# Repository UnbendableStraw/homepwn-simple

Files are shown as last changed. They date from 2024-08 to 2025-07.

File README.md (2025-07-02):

# Simple HomePod USB / UART Adapter 
This is a forked / modified repo of el1ng's and tihmstar's homepod adapters. I've modified it to fit different test probes since the E2/B1 probes tend to poke holes. I reverted the shape  of the adapter back to a circle. The alignment tabs are now properly aligned and enabled. The screw holes are now properly lined up. The location of the pin holes also needed slight tweaking, and by widening the width of the pin box it makes a perfect fit!

Also included is my table stand. This can be used as a base to sit your homepod on when upside-down, to prevent scratches on the plastic top. It can also be used to protect the dongle when homepod is placed upright, to support USB Airplay (since the adapter will stick out the bottom and not let the HomePod sit flat on a table)

I sell both of these if you don't want to try making them yourself: https://nicsfix.com/shop

## You Will Need
* 4x M2x6 screws; to screw the adapter plate to the bottom of the homepod. You can tape it down if it is secure. The point is a SECURE connection. The screws that hold the circular plastic frame on top of the logic board work perfectly if you have any spares.
* Pogo pins / test probes (I recommend P75-D2 or P75-J1, I do not recommend the E2 or B1 needle probes, they will poke holes in your pads)
* USB cable to solder to test probes
* If using UART, spare wire to solder to UART test probes, and a USB to **1.8v** UART serial adapter. Recommended to use an adapter with a genuine FTDI chip, like the "DSD TECH SH-U09C5".

# Making It
I hosted a livestream making some adapters if you want some visual reference, not really a guide: https://www.youtube.com/watch?v=fxdIzLTcSnA

Download the Table_Dock_v1.1.1, load it into your preferred slicer, with the homepod side of the dongle facing up, and with support. Then print it!

As shown in the livestream, push the pins into the adapter until the tube of the pogo pin is flush with the adapter.

The pinout of the HomePod's debug port, with the pod upside down, and you looking down at the port, is as follows:

```
                AC PORT
                  ^
                  
| NC | TX | RX | CTRL | D+ | D- | GND |
| NC | NC | NC | GND  | NC | NC | NC  |
```
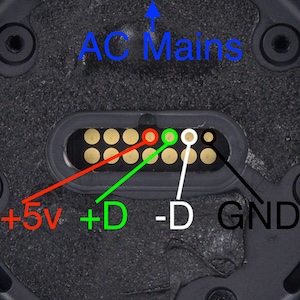
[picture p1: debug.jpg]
pinout


For USB and restoring software, you only need four probes connected to +5v, D+, D-, GND. 

For UART, you need two more probes on the TX and RX, and one for GND. You can share the same GND from the USB line, or another marked GND pad, all the GND pads are internally connected. This is ONLY 1.8v! 3.3 or 5v can cause damage.
 
If you're using probes like the E2 probes, you won't be able to fit the probes in with wires attached, so you'll have to insert the pins into the adapter first, then solder the wires onto them. 

# Using It

You can use this adapter to restore a software bricked first generation HomePod via the restore guide: https://github.com/UnbendableStraw/homepod-restore/

You can also look at the UART console to possibly identify hardware failures preventing the software from operating. To do so;
1. Find your USB UART adapter's address with

`ls /dev/cu.*`

2. "Screen" into your adapter (probably using baud rate 115200) with this, where `tty.usbserial-1` is the adapter you got from the previous command

`screen /dev/tty.usbserial-1 115200`

Tip: You can output your UART logs to a file while still being able to see the logs as they happen. After you enter your screen command, hit control-a, then H. It will output a screenlog.0 file you can rename to .txt

# Warning

If the wrong pins on your adapter touch the wrong pads on the homepod while there is power, it can cause hardware damage. Avoid by simply disconnecting power and usb from pod before removing the adapter from pod.

# USB Airplay for A1639 Apple HomePods

First-generation Apple HomePods can be connected via USB to a Mac and function as a local "USB" Airplay 2 Speaker. This is still Airplay, with all it's pros / cons, just over USB. The HomePod / Mac appear to be creating a virtual network adapter over the USB connection. 

Observations / limitations so far:
* Only seems to work on Macs
* Only seems to work if the HomePod is already set-up. Does not work on a HomePod in Setup Mode
* Does not seem to work if the HomePod is configured as a "Default Output" for an Apple TV
* Needs at least least HomePod Version 14.0? 13.X did not work, so I assume older versions also won't work
* Can play to multiple HomePods via USB using "Airfoil" by Rogue Amoeba (plus other Airplay 2 speakers.) 
* Connecting a stereo-paired HomePod via USB will only play audio to the USB HomePod
* USB Ethernet adapters, even powered ones, by themselves do not appear to work with the HomePod.
* You can turn off all of your wireless radios and it will still work since this is all over the USB cable. 
* Your HomePod's WiFi can be completely dead and this will still work, if your HomePod is already configured.

To use, you need to make or buy a USB adapter for your pod. Whatever you end up doing to get USB access to your HomePod will most likely stick out the bottom, so you need to raise the base of the pod to prevent damage to the adapter or debug port when placing it upright on a table. I have 3d printable adapters and stands you can make or buy here: https://github.com/UnbendableStraw/homepwn-simple/

Video Demos:
* https://twitter.com/UnbendableStraw/status/1836576917077790951
* https://twitter.com/UnbendableStraw/status/1836848399997620624
* https://youtube.com/live/Je3FnzLNufg

Unknowns:
* Can we get a Mac bridge the connection to the rest of your network?
* Can we get it working on Windows / Linux? 
* Can we get _any_ ethernet adapter to work with this?
* Will updates break / remove this in the future?

# Give Up?

You can buy premade adapters, stands, and docks here https://nicsfix.com/shop

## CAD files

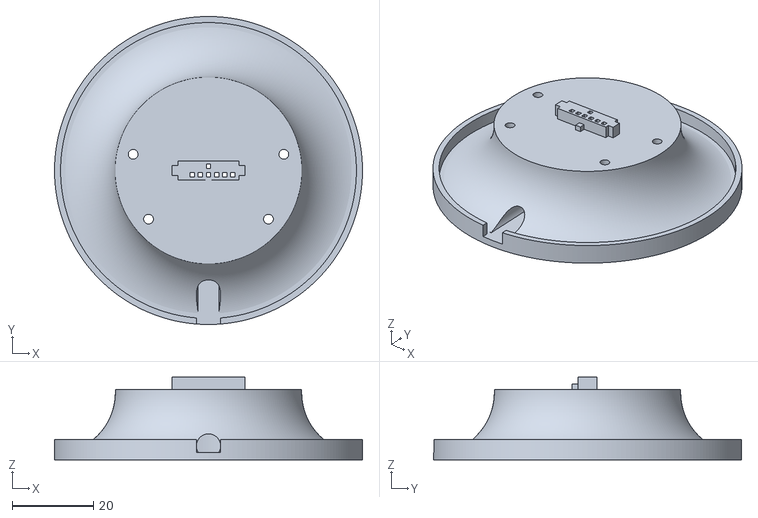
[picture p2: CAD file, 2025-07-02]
Table_Dock_v1.1.1.stl
76.0 x 76.0 x 20.4

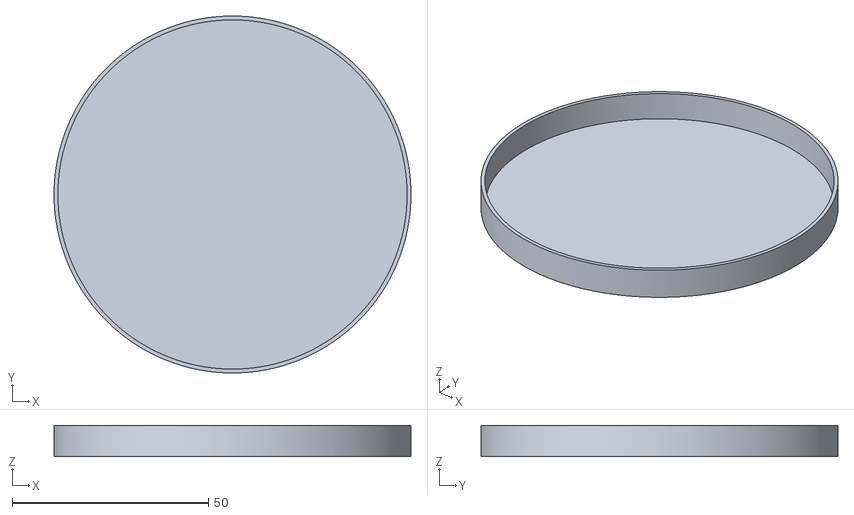
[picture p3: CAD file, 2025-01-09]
TableDockv1_Cap.stl
91.0 x 91.0 x 8.00

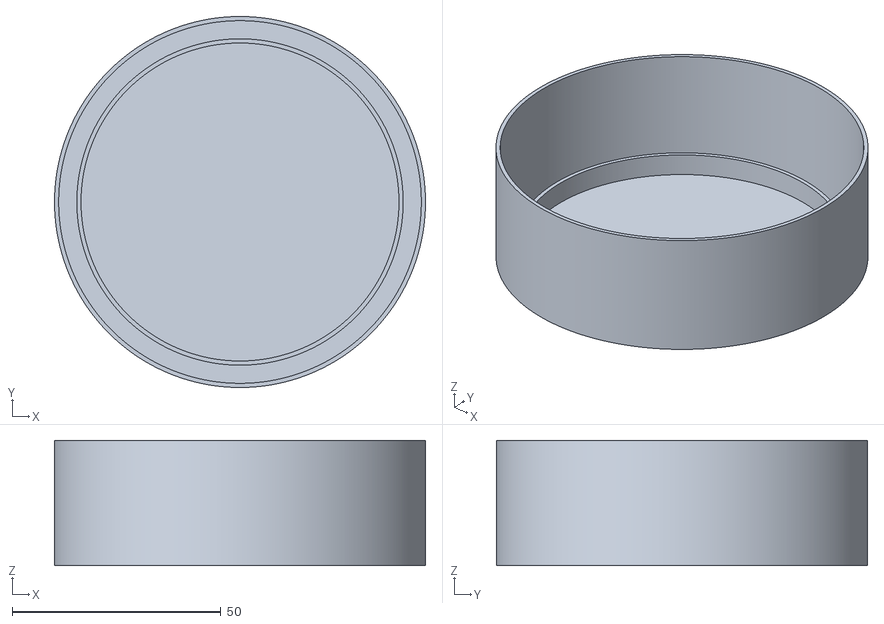
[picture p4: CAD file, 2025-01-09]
TableDockv1_BottomCase.stl
88.8 x 88.8 x 30.0

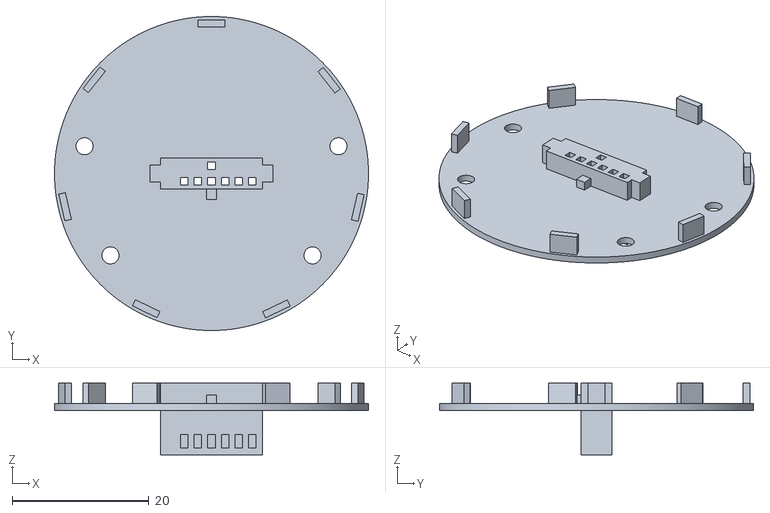
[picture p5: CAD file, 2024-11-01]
Adapterv2.stl
46.0 x 46.0 x 10.5

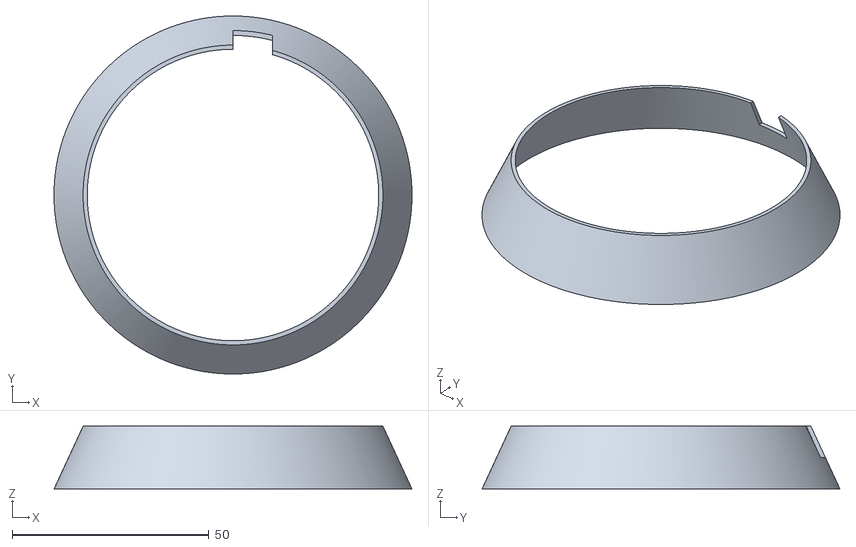
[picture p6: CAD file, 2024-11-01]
TableStand_v3.stl
91.0 x 91.0 x 16.0

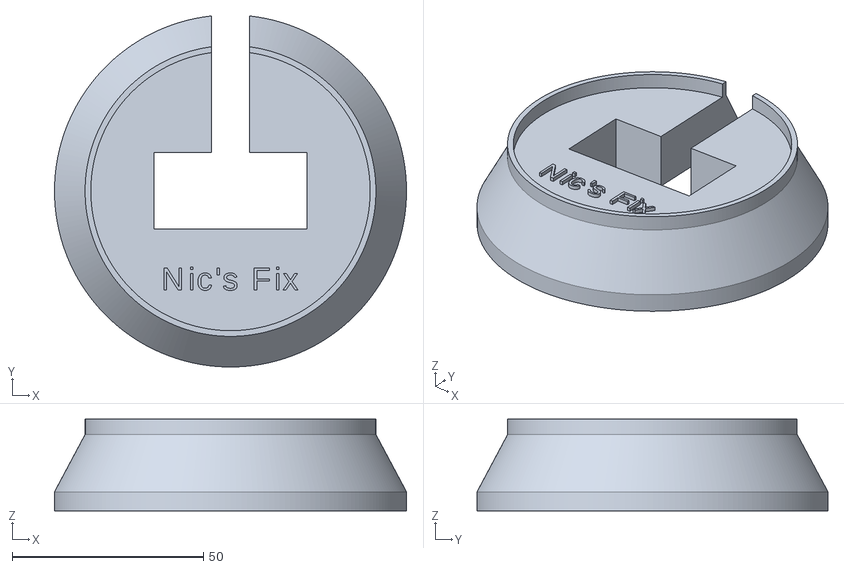
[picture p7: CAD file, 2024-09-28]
table_stand.stl
92.0 x 91.7 x 24.0

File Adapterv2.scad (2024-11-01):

box_length = 15;
box_width = 4.6;
box_height = 5;
box_height_extra = 5.5;
pin_pad = 0.5;
pin_width = 1.1;
nop_width = 1.5;
nop_height = 2;
sidepin_width = 2.5;

// Parameters

base_z_height = 1;

hole_diameter = 2.5;  // Diameter of the holes
hole_depth = 100;    // Depth of the holes (adjusted to be less than the cylinder height)
hole_positions = [
    [14.8, 12],  // Position of hole 1 (x, y)
    [-14.8, 12], // Position of hole 2 (x, y)
    [18.6, -4],  // Position of hole 3 (x, y)
    [-18.6, -4]  // Position of hole 4 (x, y)
];

hole2_diameter = 44;  // Diameter of the holes
hole2_depth = 18;    // Depth of the holes (adjusted to be less than the cylinder height)
hole2_positions = [
    [0, 0, 10]  // Position of hole 4 (x, y, z)
];

// Parameters for the base
top_diameter = 70;
bottom_diameter = 76;
wall_thickness = 1;
top_thickness = 0; // Thickness of the top surface
curve_radius = 15; // Radius of the curve
cutout_position_z = 0; // Z position of the cut-out (make this adjustable)
cutout_height_adjustable = 0.8; // Adjust the height of the cut-out (new parameter)
// New parameter for adjustable base thickness
base_thickness = 0; // Adjust this value to change the thickness of the base

// Parameters for the new ring
ring_height = 4; // Height of the ring
ring_thickness = 2; // Thickness of the ring
ring_inner_diameter = 73; // Inner diameter of the ring
ring_outer_diameter = 76; // Outer diameter of the ring (same as top_diameter)

// Parameters for the cutout in the ring
cutout_position_x = 0; // X position of the cutout center
cutout_position_y = 70; // Y position of the cutout center
cutout_width_in_ring = 4; // Width of the cutout
cutout_height_in_ring = 70; // Height of the cutout (increased to ensure full cut through)

// Set number of facets for smoother cylinders
$fn = 200; // Increases the number of segments to make the cylinder smooth

// Parameters for the bottom ring (same as the top ring)
bottom_ring_height = 2; // Height of the bottom ring
bottom_ring_thickness = 3; // Thickness of the bottom ring
bottom_ring_inner_diameter = 44; // Inner diameter of the bottom ring (same as ring_inner_diameter)
bottom_ring_outer_diameter = 76; // Outer diameter of the bottom ring (same as bottom_diameter)

// Parameters for the top ring =
top_ring_height = 5; // Height of the top ring
top_ring_inner_diameter = 73; // Inner diameter of the top ring (same as ring_inner_diameter)
top_ring_outer_diameter = 76; // Outer diameter of the top ring (same as top_diameter)
module holebox(x = 0, y = 0, z = 0, withHoles = 1){
    translate([x,y,z+1.5]){
        difference(){
            translate([0,0,box_height_extra/2])
            cube([box_length, box_width, box_height+box_height_extra], center = true);
        
            if (withHoles != 0){
                for ( i = [-3 : 3]){
                    if (i != -3){
                        translate([i*2, box_width/2-1.2, 0])
                            cube([pin_width, pin_width, box_height+1+box_height_extra*2], center = true);
                        
                        //sideholes
                        translate([i*2-pin_width/2,box_width/2-1,box_height])
                            cube([pin_width,1,2]);
                    }
                    if (i == 0)
                    translate([i*2, -(box_width/2-1.2), 0])
                        cube([pin_width, pin_width, box_height+1+box_height_extra*2], center = true);
                }
            }
        }
        

        //pin
        translate([0, box_width/2 + nop_width/2, box_height/2-nop_height/2 - pin_pad-0.8])
            cube([nop_width, nop_width, nop_height], center = true);
        translate([0, box_width/2 + nop_width/2, box_height/2-nop_height/2-1])
            cube([nop_width, nop_width, nop_height], center = true);
        
        
        //sidepin right
        translate([box_length/2 + nop_width/2, 0, -0.5])
            cube([nop_width, sidepin_width, box_height-1], center = true);

        //sidepin left
        translate([-(box_length/2 + nop_width/2), 0, -0.5])
            cube([nop_width, sidepin_width, box_height-1], center = true);
        
    }
}

support_len = 2;
support_width = 4;
thickness = 1;

module foot(x = 0, y = 0, z = 0){
    
    leg_len = 3;
    
    translate([x-support_width/2,y-support_len/2,z]){
        translate([0,0,1]);

      


        
        translate([0,-0.5,-3])
        rotate([0,0,0]){
            translate([0,0,-leg_len+2])
                cube([support_width,thickness,leg_len]);                    
        }

    }
}

module footstuff(x = 0, y = 0, z = 1){
    plate_length = box_width + 0;
    plate_width = box_length + 0;
    plate_thickness = 0;
    
    plate_conn = 0;
    
    fplate_radius = 21;

    
    translate([x,y,z]){
    

        



        for ( i = [0:6]){
            rotate([180,0,51.4*i])
                foot(0,-fplate_radius,nop_height);            
        }

    }
}
translate([0, 0, +base_z_height]) {
rotate([0, 0, 0]) {
footstuff();
}
}


module hole(x = 0, y = 0, z = 0){
    translate([x,y,z-1]){
        cylinder(3,1.25,1.25);
    }
}



module base() {
    difference() {
        // Outer part (smooth cone)
        color("lightblue") {
            // Create the smooth cone for the main body
            cylinder(h = base_z_height, r1 = bottom_diameter / 2, r2 = top_diameter / 2);
        }
       // Subtract the curved cut-out from the base without flipping
translate([0, 0,  cutout_position_z]) {
    rotate_extrude($fn = 200)
        translate([bottom_diameter / 2, 0, 0])
            offset(r = curve_radius) {
                // Adjust the height of the cut-out without flipping
                square([curve_radius, cutout_height_adjustable], center = false);
            }
}
    // Cutting hole: a cylinder
    translate([0, -10, 13.1])
    rotate([90,0,900])// Move the cylinder to pass through the cube
    cylinder(h=50, r=2.5, center=false);  // A vertical cylinder with radius 5
            //cut holes out for pins
            translate([0,0,0])
            cube([box_length, box_width, box_height+box_height_extra], center = true);
        
            
                for ( i = [-3 : 3]){
                    if (i != -3){
                        translate([i*2, box_width/2-1, 0])
                            cube([pin_width, pin_width, box_height+1+box_height_extra*2], center = true);
                        
                        //sideholes
                        translate([i*2-pin_width/2,box_width/2-1,box_height])
                            cube([pin_width,1,2]);
                    }
                    if (i == 0)
                    translate([i*2, -(box_width/2-1), 0])
                        cube([pin_width, pin_width, box_height+1+box_height_extra*2], center = true);
                }
                                // Create holes
        for (pos = hole2_positions) {
            translate([pos[0], pos[1], pos[2]]) { // Adjusting the z position to cut through the cylinder
                cylinder(hole2_depth, hole2_diameter / 2, hole2_diameter / 2, center = true); // Create the holes
            }
        }
     // Create holes
        for (pos = hole_positions) {
            translate([pos[0], pos[1], 0]) { // Adjusting the z position to cut through the cylinder
                cylinder(hole_depth, hole_diameter / 2, hole_diameter / 2, center = true); // Create the holes
            }
        }
            
        

    }

}
translate([0, 0, +base_z_height]) {
rotate([180, 0, 0]) {
base();
}
}





rotate([180, 0, 0]) {
    holebox(0, 0, -base_z_height -2);  // Adjust z-position as necessary after flipping
}

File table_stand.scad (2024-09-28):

// Parameters for the base
base_z_height = 15; // Adjustable height of the base
top_diameter = 76;
bottom_diameter = 92;
wall_thickness = 1;
cutout_width = 10;  // Width of the wire cutout (adjusted from diameter)
cutout_length = 10;  // Length of the wire cutout
cutout_depth = 6; // Depth of the cutout from the edge
cutout_height = 20; // Depth of the cutout into the Z axis
top_thickness = 0.6; // Thickness of the top surface

// New parameter for adjustable base thickness
base_thickness = 0; // Adjust this value to change the thickness of the base

// Parameters for the rectangular cutouts
rect_cutout1_width = 40;  // Width of the first rectangular cutout
rect_cutout1_length = 20;  // Length of the first rectangular cutout
rect_cutout_height = base_z_height; // Height of the rectangular cutouts (cuts through the base)

// Parameters for the second rectangular cutout
rect_cutout2_width = 10;  // Width of the second rectangular cutout
rect_cutout2_length = 50;  // Length of the second rectangular cutout
// Position offsets for the second rectangular cutout
rect_cutout2_offset_x = 0;  // X offset for the second rectangular cutout
rect_cutout2_offset_y = 20;  // Y offset for the second rectangular cutout

// New parameter for X-axis offset of the first rectangular cutout
x_offset = -5; // Adjust this value for the X-axis offset

// Parameters for the new ring
ring_height = 4; // Height of the ring
ring_thickness = 2; // Thickness of the ring
ring_inner_diameter = 73; // Inner diameter of the ring
ring_outer_diameter = 76; // Outer diameter of the ring (same as top_diameter)

// Parameters for the cutout in the ring
cutout_position_x = 0; // X position of the cutout center
cutout_position_y = 70; // Y position of the cutout center
cutout_width_in_ring = 10; // Width of the cutout
cutout_height_in_ring = 70; // Height of the cutout (increased to ensure full cut through)

// Set number of facets for smoother cylinders
$fn = 200; // Increases the number of segments to make the cylinder smooth

// Main base shape (truncated cone with smooth sides and a top)
module base() {
    difference() {
        // Outer part (smooth cone) colored in light blue
        color("lightblue")
            cylinder(h = base_z_height, r1 = bottom_diameter / 2, r2 = top_diameter / 2);

        // Wire cutout on the top lip, extending over the edge (changed to rectangle) colored in red
        color("red")
            translate([x_offset, (top_diameter / 2) + (cutout_width / 2) - cutout_depth, base_z_height - cutout_height])
                cube([cutout_width, cutout_length, cutout_height + wall_thickness]);

        // First rectangular cutout centered on the top and cutting through the whole model colored in yellow
        color("yellow")
            translate([-rect_cutout1_width / 2, -rect_cutout1_length / 2, 0]) // Start at the bottom of the model
                cube([rect_cutout1_width, rect_cutout1_length, rect_cutout_height]);

        // Second rectangular cutout positioned by offsets and resizable colored in green
        color("green")
            translate([rect_cutout2_offset_x - rect_cutout2_width / 2, 
                       rect_cutout2_offset_y - rect_cutout2_length / 2, 
                       0]) // Start at the bottom of the model
                cube([rect_cutout2_width, rect_cutout2_length, rect_cutout_height]);
    }
    
    // Create the solid base colored in gray
    color("gray")
        translate([0, 0, -base_thickness]) // Lower the base to ensure it aligns with the ring
            cylinder(h = base_thickness, r = bottom_diameter / 2); // Adjust the height to base_thickness
}

// New ring module with a cutout
module ring() {
    difference() {
        // Outer cylinder for the ring colored in dark blue
        color("darkblue")
            cylinder(h = ring_height, r = ring_outer_diameter / 2);
        
        // Inner cylinder to create the hollow part of the ring colored in light gray
        color("lightgray")
            translate([0, 0, -1]) // Ensure the inner cut does not interfere with other features
                cylinder(h = ring_height + 2, r = ring_inner_diameter / 2);
        
        // Cutout in the ring colored in orange
        color("orange")
            translate([cutout_position_x, cutout_position_y, 1]) // Position the cutout
                cube([cutout_width_in_ring, cutout_height_in_ring, ring_height + 5], center = true); // Ensure the cut goes through fully
    }
}
// Parameters for the bottom ring (same as the top ring)
bottom_ring_height = 5; // Height of the bottom ring
bottom_ring_thickness = 2; // Thickness of the bottom ring
bottom_ring_inner_diameter = 89; // Inner diameter of the bottom ring (same as ring_inner_diameter)
bottom_ring_outer_diameter = 92; // Outer diameter of the bottom ring (same as bottom_diameter)

// New bottom ring module
module bottom_ring() {
    difference() {
        // Outer cylinder for the bottom ring colored in dark blue
        color("darkblue")
            cylinder(h = bottom_ring_height, r = bottom_ring_outer_diameter / 2);
        
        // Inner cylinder to create the hollow part of the ring colored in light gray
        color("lightgray")
            translate([0, 0, -1]) // Ensure the inner cut does not interfere with other features
                cylinder(h = bottom_ring_height + 2, r = bottom_ring_inner_diameter / 2);
                // Cutout in the ring colored in orange
        color("orange")
            translate([cutout_position_x, cutout_position_y, 1]) // Position the cutout
                cube([cutout_width_in_ring, cutout_height_in_ring, ring_height + 5], center = true); // Ensure the cut goes through fully
    }
}
// Parameters for text
text_content = "Nic's Fix";  // The text to display
font = "SF Pro Display:style=Bold"; 
text_size = 6;  // Size of the text
text_thickness = 1;  // Thickness of the text extrusion
text_spacing = 1.2;  // Spacing between letters

// Parameters for text position
text_x_offset = 29;  // Offset for moving the text along the X-axis
text_z_offset = 10;  // Adjustable Z-position for the text


// Calculate the text width for centering
text_width = text_spacing * (len(text_content) - 1) * text_size;

// Call the bottom text module


// Add mirrored text to the bottom of the object with adjustable Z-position

toptext_z_offset = 15;  // Adjustable Z-position for the text
module top_text() {
    color("black")
        translate([-(text_width / 2) + text_x_offset, -(text_size / 2), toptext_z_offset])  // Adjust X and Z positions
    translate([0,-20,0])
        linear_extrude(height = text_thickness)
            text(text_content, size = text_size, spacing = text_spacing, halign = "center", valign = "center");
}


// Call the top text module
top_text();


// Call the bottom ring module at the bottom of the base
translate([0, 0, -bottom_ring_height]) // Position the ring at the bottom of the base
    bottom_ring();

// Call the base module
base();

// Call the ring module on top of the base
translate([0, 0, base_z_height]) // Position the ring on top of the base
    ring();

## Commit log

2024-08-15 Slightly shorter version for P75-E2 probes
    [homepod_adapter_e2.scad]
2024-09-26 tweaked dimensions
    [table_stand.scad, table_stand.stl]
2024-09-27 added cutout in top lip
    [table_stand.scad, table_stand.stl]
2024-09-28 tweaked sizes to fit base better
    [table_stand.scad, table_stand.stl]
2024-10-02 Add USB Airplay info. Add UART 1.8v ONLY.
2024-10-10 add recommended uart adapter
2024-11-01 add minimal table stand design
    [TableStand_v3.stl]
2024-11-01 suggest these probes / dont recommend those probes
2024-11-01 add tweaked / refined adapter
    [Adapterv2.scad, Adapterv2.stl]
2025-01-09 Releasing my dock into the wild
    [TableDockv1_BottomCase.stl, TableDockv1_Cap.stl]
